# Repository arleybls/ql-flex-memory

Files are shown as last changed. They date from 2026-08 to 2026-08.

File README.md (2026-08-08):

# QL Flex Memory Expansion

A 512kB external RAM expansion for the Sinclair QL, based on Alvaro Alea
Fernandez's design. The circuit is unchanged. This version reworks the board to
make assembly and reconfiguration easier, hence the name.

Original project: https://github.com/alvaroalea/QL_512kb_External_Expansion

## Changes in the 2025 revision

* Standard 2.54mm pin headers replace the configuration solder jumpers. Jumper
  caps now control the memory configuration and Trump Card mode.
* The GAL16V8 uses a PLCC-20 SMD socket instead of a DIP-20 through-hole package.
  The GAL remains removable and reprogrammable while taking up less board space.
* The resistors and 100nF capacitors use the 0805 size instead of 1206.
* The silkscreen includes the memory configuration table
  (00-512kB / 01-256kB / 10-192kB / 11-128kB), NORMAL/TRUMP labels for the mode
  header, and the board dimensions.
* All fabrication outputs are in one `gerbers/` folder.

Board size (97.79 × 35.56 mm) and the circuit itself are unchanged from the
original rev 3.

## About the board

The board adds up to 512kB of static RAM (fast RAM) to the Sinclair QL.

Stacking two boards provides up to 896kB of memory, the same capacity as
Miracle's Trump Card.

Two memory expansions cannot occupy the same address range. This applies to
Jose Leandro's QBide, the Trump Card, and similar hardware.

The board has an expansion connector for additional interfaces.

The configuration headers provide four settings. The original board uses solder
jumpers instead.

* 512kB: The standard expansion for any QL.
* 256kB: Used as a second expansion to reach the QL's 896kB maximum. This setting
  conflicts with many expansion cards. Any card without configuration jumpers
  will be incompatible.
* 192kB: Similar to the 256kB setting, but leaves more address space for properly
  configured expansion cards.
* 128kB: Similar to the 256kB setting, with still more address space left for
  properly configured expansion cards.

The 128kB configuration cannot be installed alone. To use it for a total of
768kB, another expansion card must provide ROM at address E00000h. Without that
ROM, an overlap between the internal and external 128kB causes the QL ROM to
report a RAM malfunction and hang.

https://www.instagram.com/p/CZWfWcUM5mx/

The `gal` folder contains source code for GALasm:
https://github.com/daveho/GALasm

## RAM test software

`software/memtest/` contains a RAM test for checking an assembled card on the QL.
It combines a SuperBASIC front end with a 68008 machine-code core. The suite
tests the data bus, address bus, aliasing (GAL decode), March C-minus, and
checkerboard patterns. It supports a QDOS-safe mode and a destructive test of
the complete window. See
[software/memtest/README.md](software/memtest/README.md).

## Mini Trump Card compatibility

Alvaro also made the MiniTrump version of the Trump Card disk interface:
https://github.com/alvaroalea/QL_MiniTrump3. Unlike the original, the MiniTrump
does not include memory. Combining it with two of these RAM cards provides the
same functions as the original Trump Card.

Connect the 512kB card to the QL, the MiniTrump to the 512kB card, and the +256kB
card to the MiniTrump. Set this board's three-pin mode header, labelled
NORMAL/TRUMP on the silkscreen, to TRUMP so the MiniTrump can coordinate with
the second memory card.

## Credits and license

Original design (C) 2022 Alvaro Alea Fernandez, based on the work of McLeod
Ideafix, Jose Leandro, Zerover and tcat among others, with contributions from
www.va-de-retro.com

2025 revisions by ArleyJr.

Licensed under: CERN Open Hardware Licence Version 2 - Strongly Reciprocal

https://ohwr.org/cern_ohl_s_v2.txt

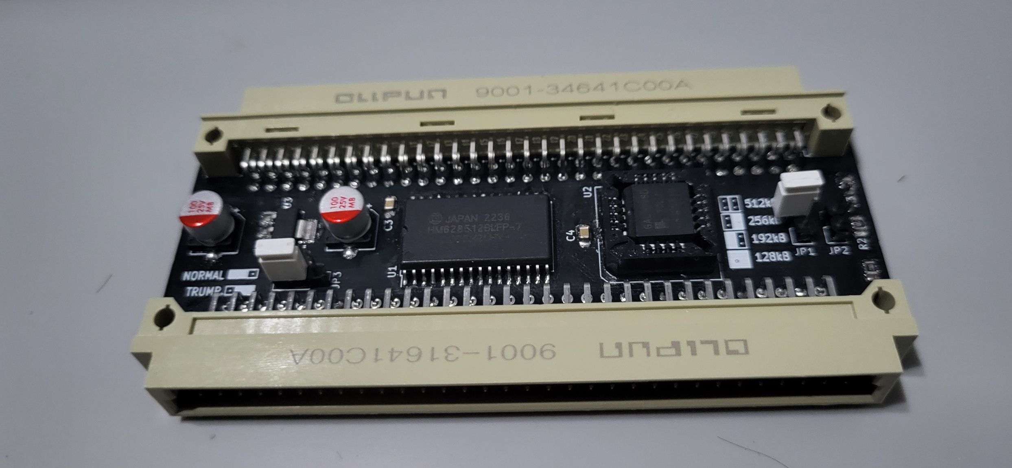
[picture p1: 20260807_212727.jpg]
QL Flex Memory Expansion board


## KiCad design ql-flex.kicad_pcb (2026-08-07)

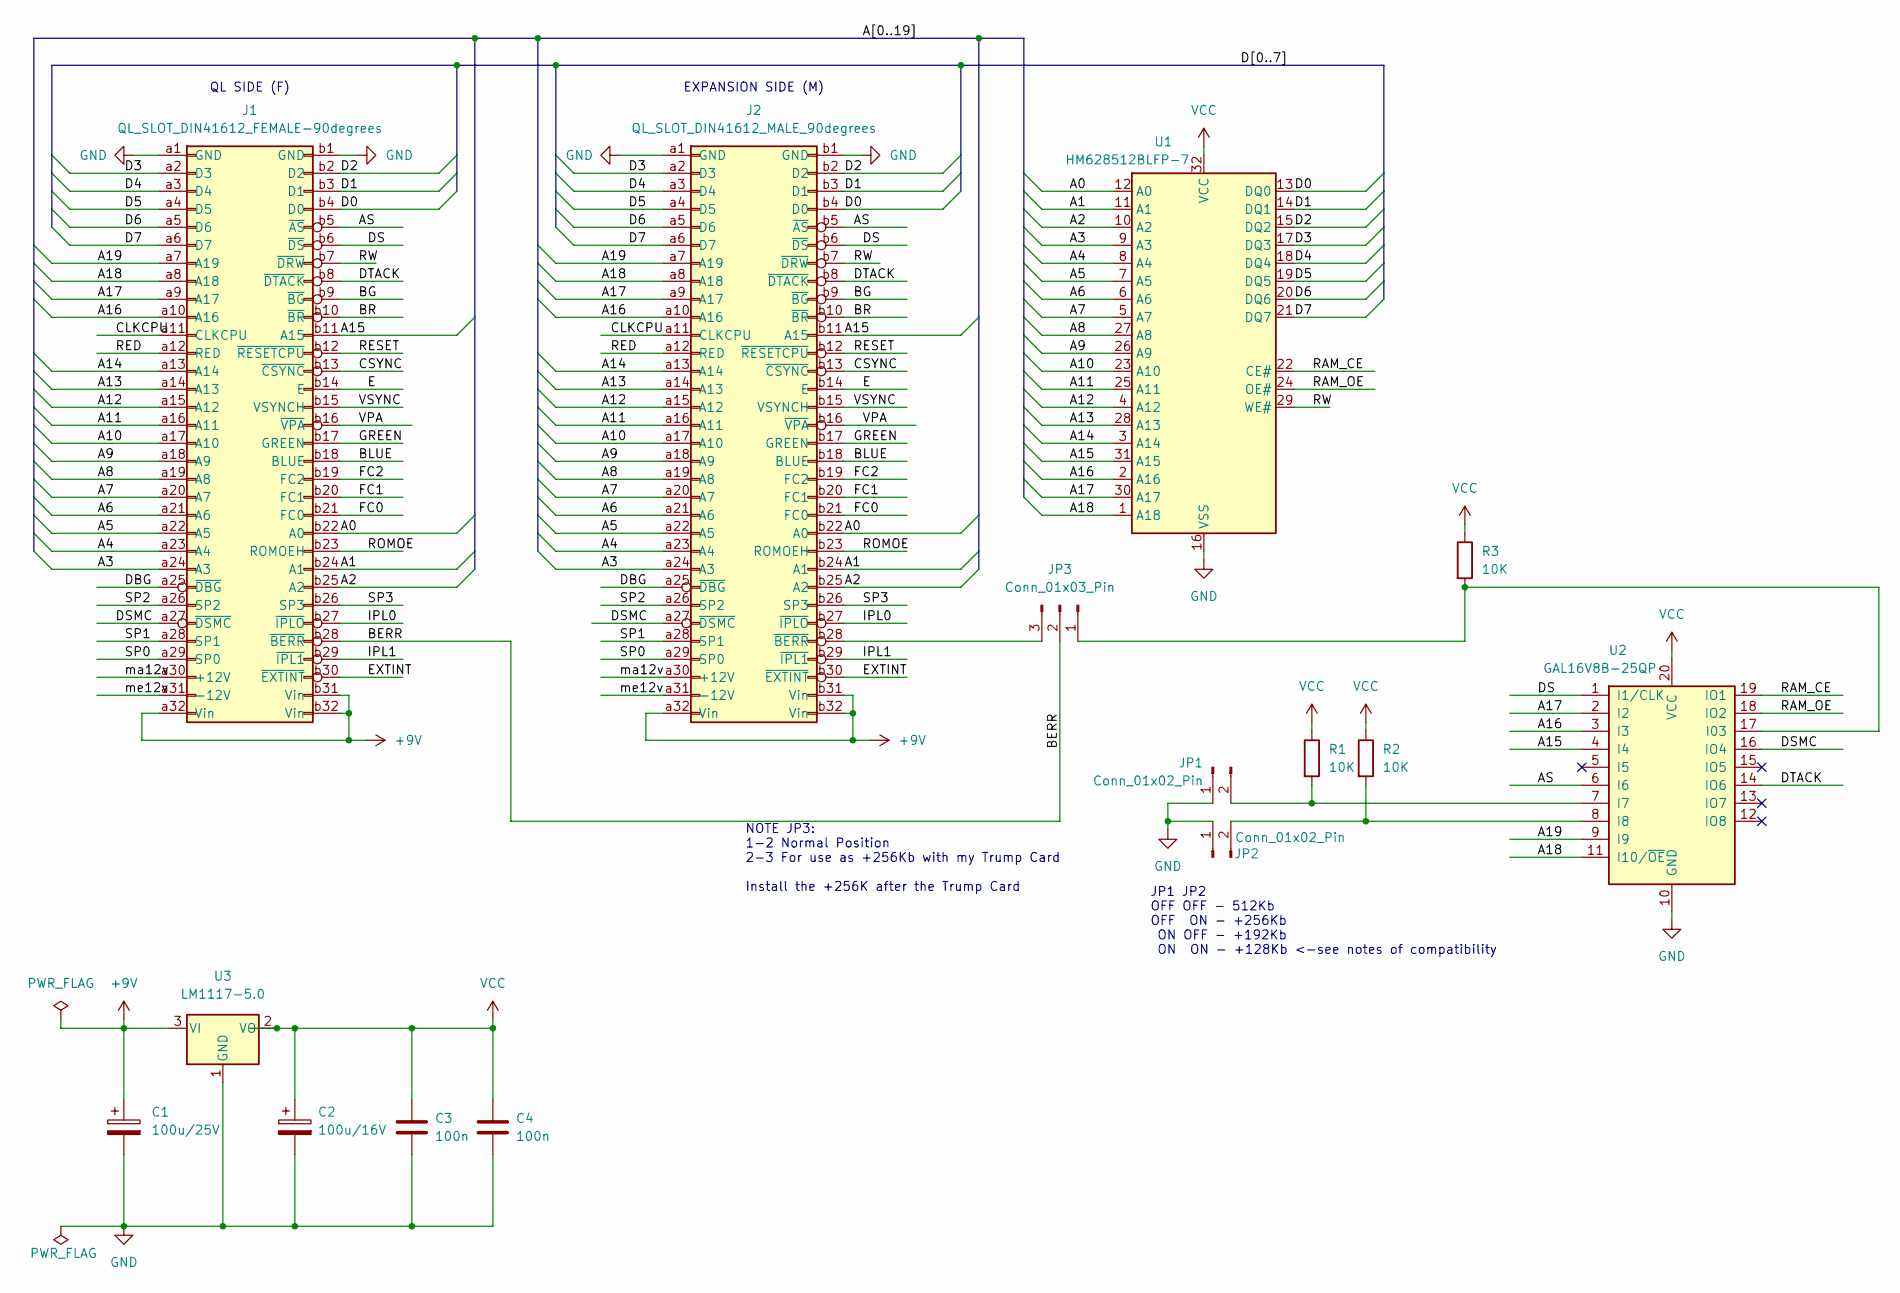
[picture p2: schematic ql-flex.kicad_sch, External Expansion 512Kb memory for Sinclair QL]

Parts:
C1: 100u/25V; CP_Elec_6.3x5.4
C2: 100u/16V; CP_Elec_6.3x5.4
C3, C4: 100n; C_0805_2012Metric_Pad1.18x1.45mm_HandSolder
J1: QL_SLOT_DIN41612_FEMALE-90degrees; DIN41612_B_2x32_Female_Horizontal_THT
J2: QL_SLOT_DIN41612_MALE_90degrees; DIN41612_B_2x32_Male_Horizontal_THT
JP1, JP2: Conn_01x02_Pin; PinHeader_1x02_P2.54mm_Vertical
JP3: Conn_01x03_Pin; PinHeader_1x03_P2.54mm_Vertical
R1, R2, R3: 10K; R_0805_2012Metric_Pad1.20x1.40mm_HandSolder
U1: HM628512BLFP-7; SSOP-32_11.305x20.495mm_P1.27mm
U2: GAL16V8B-25QP; PLCC-20_SMD-Socket
U3: LM1117-5.0; SOT-223-3_TabPin2

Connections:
+9V: C1.1, J1.a32 (Vin), J1.b31 (Vin), J1.b32 (Vin), J2.a32 (Vin), J2.b31 (Vin), J2.b32 (Vin), U3.3 (VI)
/A0: J1.b22 (A0), J2.b22 (A0), U1.12 (A0)
/A1: J1.b24 (A1), J2.b24 (A1), U1.11 (A1)
/A2: J1.b25 (A2), J2.b25 (A2), U1.10 (A2)
/A3: J1.a24 (A3), J2.a24 (A3), U1.9 (A3)
/A4: J1.a23 (A4), J2.a23 (A4), U1.8 (A4)
/A5: J1.a22 (A5), J2.a22 (A5), U1.7 (A5)
/A6: J1.a21 (A6), J2.a21 (A6), U1.6 (A6)
/A7: J1.a20 (A7), J2.a20 (A7), U1.5 (A7)
/A8: J1.a19 (A8), J2.a19 (A8), U1.27 (A8)
/A9: J1.a18 (A9), J2.a18 (A9), U1.26 (A9)
/A10: J1.a17 (A10), J2.a17 (A10), U1.23 (A10)
/A11: J1.a16 (A11), J2.a16 (A11), U1.25 (A11)
/A12: J1.a15 (A12), J2.a15 (A12), U1.4 (A12)
/A13: J1.a14 (A13), J2.a14 (A13), U1.28 (A13)
/A14: J1.a13 (A14), J2.a13 (A14), U1.3 (A14)
/A15: J1.b11 (A15), J2.b11 (A15), U1.31 (A15), U2.4 (I4)
/A16: J1.a10 (A16), J2.a10 (A16), U1.2 (A16), U2.3 (I3)
/A17: J1.a9 (A17), J2.a9 (A17), U1.30 (A17), U2.2 (I2)
/A18: J1.a8 (A18), J2.a8 (A18), U1.1 (A18), U2.11 (I10/~OE)
/A19: J1.a7 (A19), J2.a7 (A19), U2.9 (I9)
/AS: J1.b5 (~AS), J2.b5 (~AS), U2.6 (I6)
/BERR: J1.b28 (~BERR), JP3.2
/BG: J1.b9 (~BG), J2.b9 (~BG)
/BLUE: J1.b18 (BLUE), J2.b18 (BLUE)
/BR: J1.b10 (~BR), J2.b10 (~BR)
/CLKCPU: J1.a11 (CLKCPU), J2.a11 (CLKCPU)
/CSYNC: J1.b13 (~CSYNC), J2.b13 (~CSYNC)
/D0: J1.b4 (D0), J2.b4 (D0), U1.13 (DQ0)
/D1: J1.b3 (D1), J2.b3 (D1), U1.14 (DQ1)
/D2: J1.b2 (D2), J2.b2 (D2), U1.15 (DQ2)
/D3: J1.a2 (D3), J2.a2 (D3), U1.17 (DQ3)
/D4: J1.a3 (D4), J2.a3 (D4), U1.18 (DQ4)
/D5: J1.a4 (D5), J2.a4 (D5), U1.19 (DQ5)
/D6: J1.a5 (D6), J2.a5 (D6), U1.20 (DQ6)
/D7: J1.a6 (D7), J2.a6 (D7), U1.21 (DQ7)
/DBG: J1.a25 (~DBG), J2.a25 (~DBG)
/DS: J1.b6 (~DS), J2.b6 (~DS), U2.1 (I1/CLK)
/DSMC: J1.a27 (~DSMC), J2.a27 (~DSMC), U2.16 (IO4)
/DTACK: J1.b8 (~DTACK), J2.b8 (~DTACK), U2.14 (IO6)
/E: J1.b14 (E), J2.b14 (E)
/EXTINT: J1.b30 (~EXTINT), J2.b30 (~EXTINT)
/FC0: J1.b21 (FC0), J2.b21 (FC0)
/FC1: J1.b20 (FC1), J2.b20 (FC1)
/FC2: J1.b19 (FC2), J2.b19 (FC2)
/GREEN: J1.b17 (GREEN), J2.b17 (GREEN)
/IPL0: J1.b27 (~IPLO), J2.b27 (~IPLO)
/IPL1: J1.b29 (~IPL1), J2.b29 (~IPL1)
/RAM_CE: U1.22 (CE#), U2.19 (IO1)
/RAM_OE: U1.24 (OE#), U2.18 (IO2)
/RED: J1.a12 (RED), J2.a12 (RED)
/RESET: J1.b12 (~RESETCPU), J2.b12 (~RESETCPU)
/ROMOE: J1.b23 (ROMOEH), J2.b23 (ROMOEH)
/RW: J1.b7 (~DRW), J2.b7 (~DRW), U1.29 (WE#)
/SP0: J1.a29 (SP0), J2.a29 (SP0)
/SP1: J1.a28 (SP1), J2.a28 (SP1)
/SP2: J1.a26 (SP2), J2.a26 (SP2)
/SP3: J1.b26 (SP3), J2.b26 (SP3)
/VPA: J1.b16 (~VPA), J2.b16 (~VPA)
/VSYNC: J1.b15 (VSYNCH), J2.b15 (VSYNCH)
/ma12v: J1.a30 (+12V), J2.a30 (+12V)
/me12v: J1.a31 (-12V), J2.a31 (-12V)
GND: C1.2, C2.2, C3.2, C4.2, J1.a1 (GND), J1.b1 (GND), J2.a1 (GND), J2.b1 (GND), JP1.1, JP2.1, U1.16 (VSS), U2.10 (GND), U3.1 (GND)
unnamed: J2.b28 (~BERR), JP3.3
unnamed: JP1.2, R1.2, U2.7 (I7)
unnamed: JP2.2, R2.2, U2.8 (I8)
unnamed: JP3.1, R3.2, U2.17 (I03)
VCC: C2.1, C3.1, C4.1, R1.1, R2.1, R3.1, U1.32 (VCC), U2.20 (VCC), U3.2 (VO)

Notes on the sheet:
NOTE JP3: 1-2 Normal Position 2-3 For use as +256Kb with my Trump Card Install the +256K after the Trump Card
EXPANSION SIDE (M)
JP1 JP2 OFF OFF - 512Kb OFF ON - +256Kb ON OFF - +192Kb ON ON - +128Kb <-see notes of compatibility
QL SIDE (F)

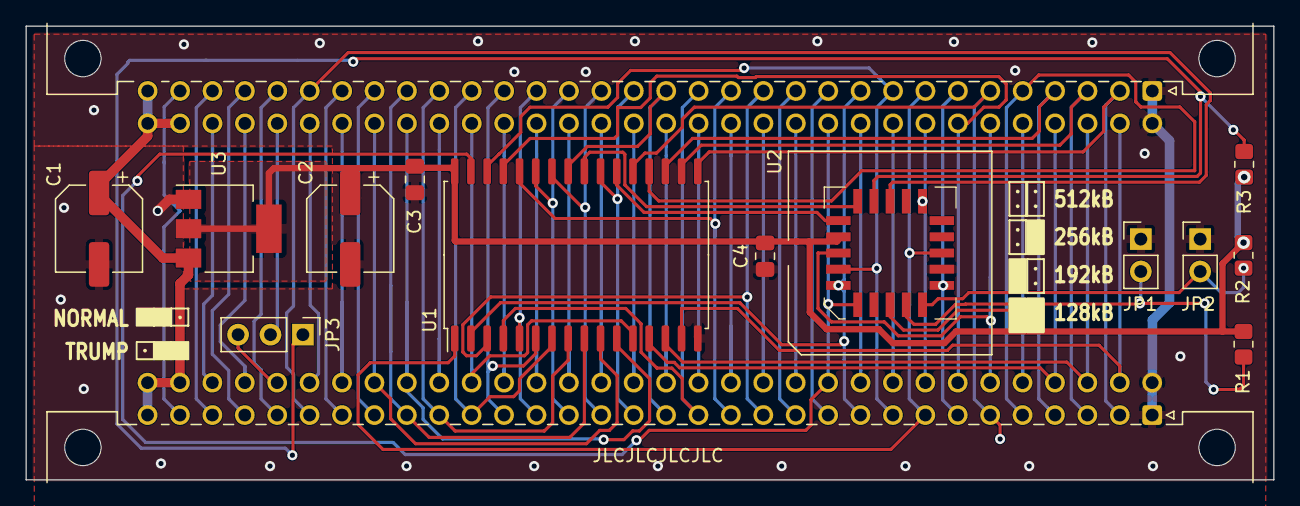
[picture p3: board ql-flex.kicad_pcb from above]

Board: 2 copper layers, 97.8 x 35.6 mm, 15 parts (0 on the bottom side), 68 nets.

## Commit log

2026-08-07 Initial commit: QL Flex Memory Expansion
    512kB external RAM expansion for the Sinclair QL, based on the design by
    Alvaro Alea Fernandez (CERN-OHL-S v2). This variant uses pin headers for
    configuration, a PLCC-20 socket for the GAL, and 0805 passives.
    [qlexternal512kram_MIX-B_Cu.gbr, qlexternal512kram_MIX-B_Mask.gbr, qlexternal512kram_MIX-B_Paste.gbr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]
2026-08-07 Rename project files to ql-flex, add interactive BOM
    Renamed qlexternal512kram_MIX.* KiCad files and gerber outputs to
    ql-flex.*, and added an interactive HTML BOM in ibom/.
    [ql-flex-B_Cu.gbr, ql-flex-B_Mask.gbr, ql-flex-B_Paste.gbr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]
2026-08-07 Update schematic title block with new project name and copyright
    [ql-flex.kicad_sch]
2026-08-08 Splash screen, auto-detect core device, copyright
    - Splash on load: full-width window with the QL Flex logo (figlet
    calgphy2), double-size 'Memory Tester' and (C) 2026 Arley Silveira;
    3 s or keypress, then wiped
    - The device prompt is gone: a 28-byte POKEd IO.OPEN probe checks
    flp1/mdv1/win1/flp2/mdv2/ram1 for memtest_bin and picks the first
    hit (result pointer kept pc-relative - sQLux's fs hook does not
    preserve A1 across TRAP #2); prompt only as fallback
    - Copyright notices in the BASIC/asm headers and README
    Debugging notes: splash loop was originally named 'spl', which
    collides with Toolkit II's SPL command - renamed sprow.
2026-08-09 memtest: one-line test status with tick/X/spinner
    The destructive screen listed each test on its own row with a RUN marker
    replaced by PASS or FAIL nn. Put all five on a single line instead, as
    NAME [x] pairs, where the bracket holds a spinner while the test runs, a
    green tick once it has passed every pass so far, or a red X once one has
    failed.
    Long linear sweeps (March C- and the checkerboard fill/verify) now run in
    32K slices so the spinner keeps moving through them, and the retention
    delay ticks it too. The slicing does not change which addresses each
    sweep covers.
2026-08-09 memtest: drop TESTS FINISHED a row and blink it
    Move the finished text from panel row 2 to row 3, leaving a blank row
    under the pass counter, and have the destructive halt loop blink it by
    alternating fin_line with a pline wipe instead of spinning on itself.
    Roughly a second per cycle, timed by a busy loop since the destructive
    run has interrupts masked.
2026-08-12 memtest: auto-detect the test window; blink the safe-mode finish
    Drop the jumper-config menu option. The window and destructive tests
    now probe 32K blocks above the QDOS RAM top and report the detected
    window with the matching config name (including TRUMP variants) before
    running.
    The safe-mode overlay now blinks TESTS FINISHED while waiting, via a
    new core entry at +20 (version 5), with a blank row before PRESS ENTER
    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
2026-08-12 Add Level-0 pseudo-ROM loader (romload)
    SuperBASIC loader that probes for the card's unclaimed top window,
    validates the ROM image (size, $4AFB0001 header) and LBYTES it at the
    16K-aligned window start, ready for a warm-reset ROM scan. Includes a
    vasm-assembled QDOS helper stub (FS.HEADR + MT.INF) as DATA words with
    its source.
2026-08-12 memtest: confirm before running the window test
    The window probe can be fooled on real hardware (floating bus reads
    echo ULA video fetches; a decode fault can present a phantom window
    whose access hangs the machine). Show the detected window, warn when
    it matches no known config, and ask before testing it.

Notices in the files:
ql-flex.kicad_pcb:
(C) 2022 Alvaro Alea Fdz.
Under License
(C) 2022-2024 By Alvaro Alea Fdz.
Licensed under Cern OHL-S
